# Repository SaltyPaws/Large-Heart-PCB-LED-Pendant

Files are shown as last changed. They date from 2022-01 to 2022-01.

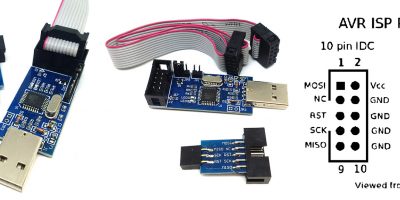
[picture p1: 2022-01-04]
images/usbasp_header-400x200.jpg

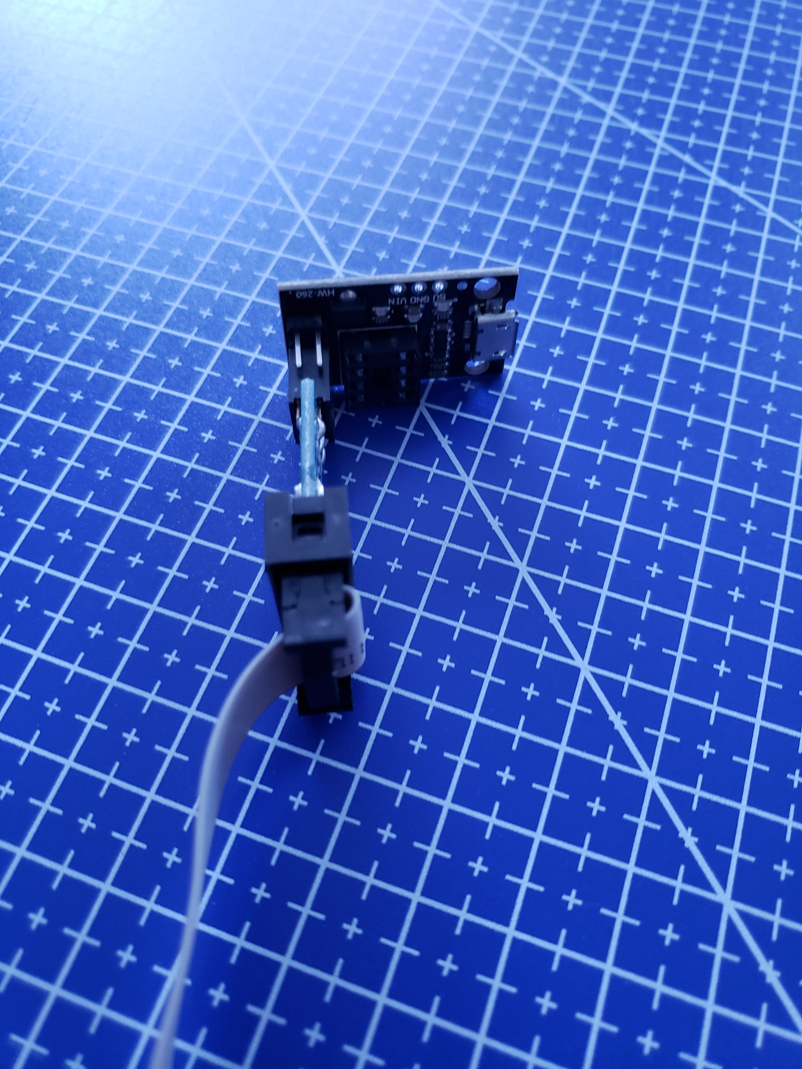
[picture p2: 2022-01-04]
images/20220103_123011.jpg

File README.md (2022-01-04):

# Large LED Heart PCB Pendant
> A large heart with 20 individually controllable LEDS using 4 pins on an ATtiny 45 with Charlieplexing
> This is an easy to solder project, as all components are trough hole, except for the large and easy to solder battery holder
> Who would not like to be pledged eternal love to by their valentine giving them a large blinky LED heart Pendant!

Large HEART PCB LED Pendant

## Table of Contents
* [General Info](#general-information)
* [Technologies Used](#technologies-used)
* [Features](#features)
* [Images](#images)
* [Setup](#setup)
* [Usage](#usage)
* [Project Status](#project-status)
* [Room for Improvement](#room-for-improvement)
* [Acknowledgements](#acknowledgements)
* [Contact](#contact)
<!-- * [License](#license) -->

## General Information
- I developed this project, in order to introduce my daughters to electronics. This pendant can be used to introduce STEAM concepts at many levels. It can be used to introduce electronics, teach trough hole assembly/soldering and programming.
- This is a basic demonstration of the Charlieplexing principle. The heart can be used stand alone or in a pendant.
- I used FreeCAD in order to design the heart shape. Unfortunately at the time of designing, the offset tool was not available in FreeCAD (I know there are work arounds), and I completed the snap on case design using Fusion360.
- I skipped the breadboard prototyping phase by using the proven Circuit design from designer2k2. The first version of the PCB worked as per design.
- For printing the case, I used PLA, 40% infill and 0.2mm layer height. It easily snaps onto the PCB, and while the stand offs include m3 thread, the M3 x6mm bolts are not required as the 45 degrees edge on the case holds it in place. I would not reccomend using without case as the back of a trough hole PCB can be demanding blood like a Vampire from Transylvania.
<!-- You don't have to answer all the questions - just the ones relevant to your project. -->

## Technologies Used
- Ubuntu 20.10 OS
- FreeCAD Realthunder branch (2021.10.15) for designing the heart shape
- KiCad 5.99.0+really5.1.10+dfsg1-1, release build
- Freerouting 1.4.5 (Current KiCad does not have an autorouter)
- Fusion 360 for designing the heart case
- Prusa slicer (1.4.0)
- Arduino IDE 1.8.19 for flashing firmware and uploading the code.
- Attiny core library (https://github.com/SpenceKonde/ATTinyCore)

## Features
This project has the following awesome features:
- uses 5 pins, in order to individually control 20 LEDs
- The project uses trough hole components (with exception of easy to solder battery holder for easy assembly)
- The 3D printed snap on case projects (young) fingers from the sharp spikes on the back of the trough hole PCB.
- I used the HW-260 and USBASP in order to program the ATtiny45. However, the ATtiny45 can also be programmed using the connector on the PCB.

## images
Large HEART PCB LED Pendant
Large HEART PCB LED Pendant
Large HEART PCB LED Pendant
Large HEART PCB LED Pendant
Large HEART PCB LED Pendant
Large HEART PCB LED Pendant
<!-- If you have screenshots you'd like to share, include them here. -->

## Setup
0) order PCB and parts (I used JLPCB, Aliexpress and Digikey)
1) Program the ATtiny45 chip using the HW-260 & USBASP programmer. You will need to flash the bootloader @1 MHZ and upload the .ino code. (https://www.instructables.com/ATtiny13AATtiny25ATtiny45ATtiny85-Programming-With/) Hint: use <CTRL>+<SHIFT>+<U> in order to upload using programmer.
2) Start printing the snap on case.
3) Heat up that iron and put the PCB together.
4) Snap on the snap on case.
5) Introduce STEAM or propose to your dearest.

## Usage
Simply switch the heart on/off as required.

## Project Status
Project is complete.

## Room for Improvement
The heart is rather large for a pendant. I may develop a smaller version based on surface mount components in the future.

Room for improvement:
- With the ATtiny 45 there is more memory space. It could be programmed to cycle trough more/longer patterns.
- An eye could be added to the 3d printed snap fit case, for pendant usage. Currently only the 3mm hole is available, which may be a bit small for strings.
- One of the M3 holes is covered by the switch. However, the case is snap fit and does not need the M3 hardware to stay in place.

## Acknowledgements
- Circuit and code was based on ATtiny Powered Christmas Tree
https://github.com/designer2k2/2d-xmas-tree
https://github.com/designer2k2/2d-xmas-tree
- USBASP pinout image from: kabelverdrahtungsschema.blogspot.com

- Many thanks to my daughters for relentless beta testing

## Contact
Created by [SaltyPaws](https://github.com/SaltyPaws) - feel free to contact me!

## License
This project is open source and available under the MIT License.

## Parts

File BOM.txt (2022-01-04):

R1-5 100 Ohm resistor (use different value for different colors)
R6 10k Ohm resistor
C1 10 10μF capacitor (106)
D1-20 5mm LEDs. I used alternating white and blue extra clear
BT1/2 BS10 Battery holder
SW1 EG2585-ND (Digikey)
Attiny ATTINY45-20PU

Programming
HW-260 ATtiny13A / ATtiny25 / ATtiny45 / ATtiny85 Pluggable ATTINY Development Programming Bare Board
USBASP programmer
USBASP 10 to 6 cable converter

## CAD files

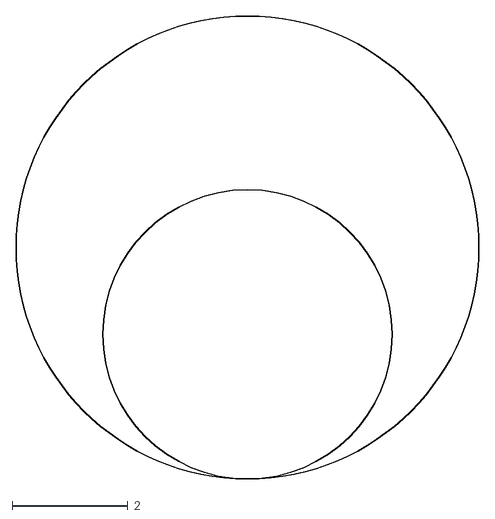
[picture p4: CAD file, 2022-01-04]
3D Print CAD/heart_v4-BodySketch.dxf
8.00 x 8.00

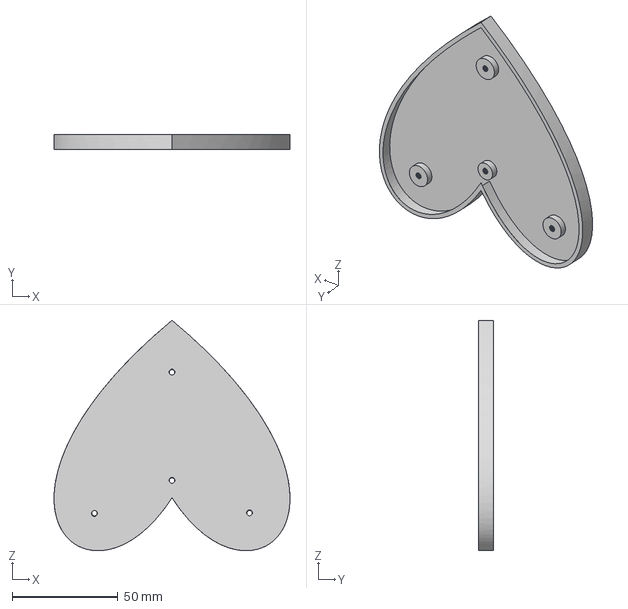
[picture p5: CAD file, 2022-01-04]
3D Print CAD/Heart_Case.step
111.7 x 7.00 x 109.1 mm

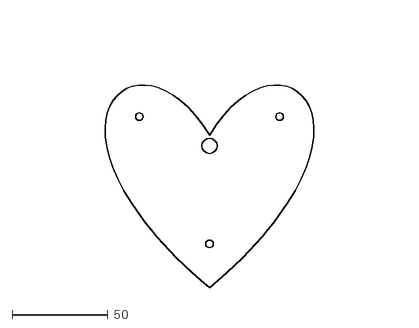
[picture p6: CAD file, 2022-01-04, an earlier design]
3D Print CAD/heart_v3-BodySketch.dxf
202.4 x 142.2

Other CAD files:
3D Print CAD/heart_v2.FCStd
3D Print CAD/heart_v1.FCStd
3D Print CAD/Heart_Case.3mf
3D Print CAD/Heart_Case.f3d
3D Print CAD/Heart_Case.iges

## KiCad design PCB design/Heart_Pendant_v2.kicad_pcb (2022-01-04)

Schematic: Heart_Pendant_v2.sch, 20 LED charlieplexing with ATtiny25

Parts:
BT1, BT2: Battery_Cell; Keystone_1058_1x2032-CoinCell_Inside
C1: C; 0805_Internal_Castellation
D1, D2, D3, D4, D5, D6, D7, D8, D9, D10, D11, D12, D13, D14, D15, D16, D17, D18, D19, D20: LED; 0805_Internal_Castellation
J1: ISP; Socket_Strip_Straight_2x03_Pitch2.54mm
R1, R2, R3, R4, R5: 75; 0805_Internal_Castellation
R6: 10k; 0805_Internal_Castellation
SW1: SW_SPDT; PCM12SMTR_inside
U1: ATTINY25-20SU; SOIC-8_Inside

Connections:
/MISO: J1.1, R2.2, U1.6 (PB1(MISO/DO/AIN1/OC0B/OC1A/PCINT1))
/MOSI: J1.4, R1.2, U1.5 (PB0(MOSI/DI/SDA/AIN0/OC0A/~OC1A~/AREF/P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)
/RESET: J1.5, R6.2, U1.1 (PB5(~RESET~/dW/ADC0/PCINT5))
/SCK: J1.3, R3.2, U1.7 (PB2(SCK/USCK/SCL/T0/INT0/ADC1/PCINT2))
/VCC: C1.1, J1.2, R6.1, SW1.2 (B), U1.8 (VCC)
GND: BT1.2, BT2.2, C1.2, J1.6, U1.4 (GND)
unnamed: BT1.1, BT2.1, SW1.1 (A)
unnamed: D1.1, D2.2, D3.2, D4.1, D11.2, D12.1, D17.2, D18.1, R2.1
unnamed: D1.2, D2.1, D9.2, D10.1, D15.2, D16.1, D19.2, D20.1, R1.1
unnamed: D3.1, D4.2, D5.2, D6.1, D9.1, D10.2, D13.2, D14.1, R3.1
unnamed: D5.1, D6.2, D7.2, D8.1, D11.1, D12.2, D15.1, D16.2, R4.1
unnamed: D7.1, D8.2, D13.1, D14.2, D17.1, D18.2, D19.1, D20.2, R5.1
unnamed: R4.2, U1.2 (PB3(XTAL1/CLKI/~OC1B~/ADC3/PCINT3))
unnamed: R5.2, U1.3 (PB4(XTAL2/CLKO/OC1B/ADC2/PCINT4))

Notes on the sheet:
R = Led R / 2 (current flows always through 2)
20 LED Charlieplexing

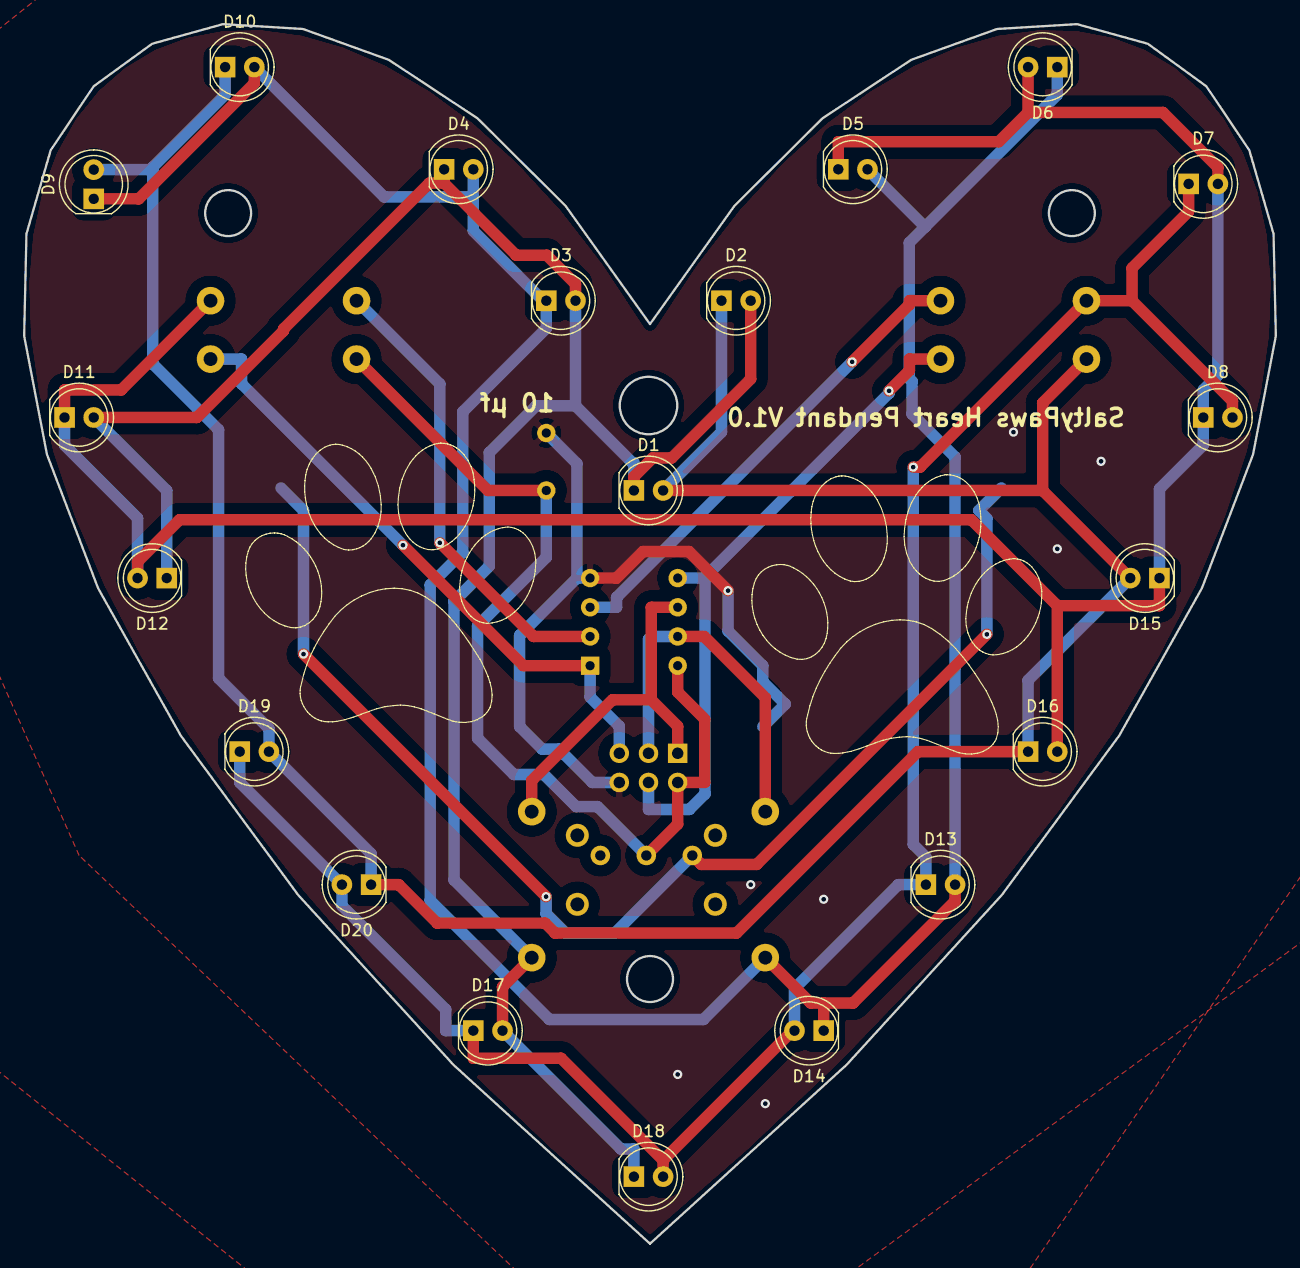
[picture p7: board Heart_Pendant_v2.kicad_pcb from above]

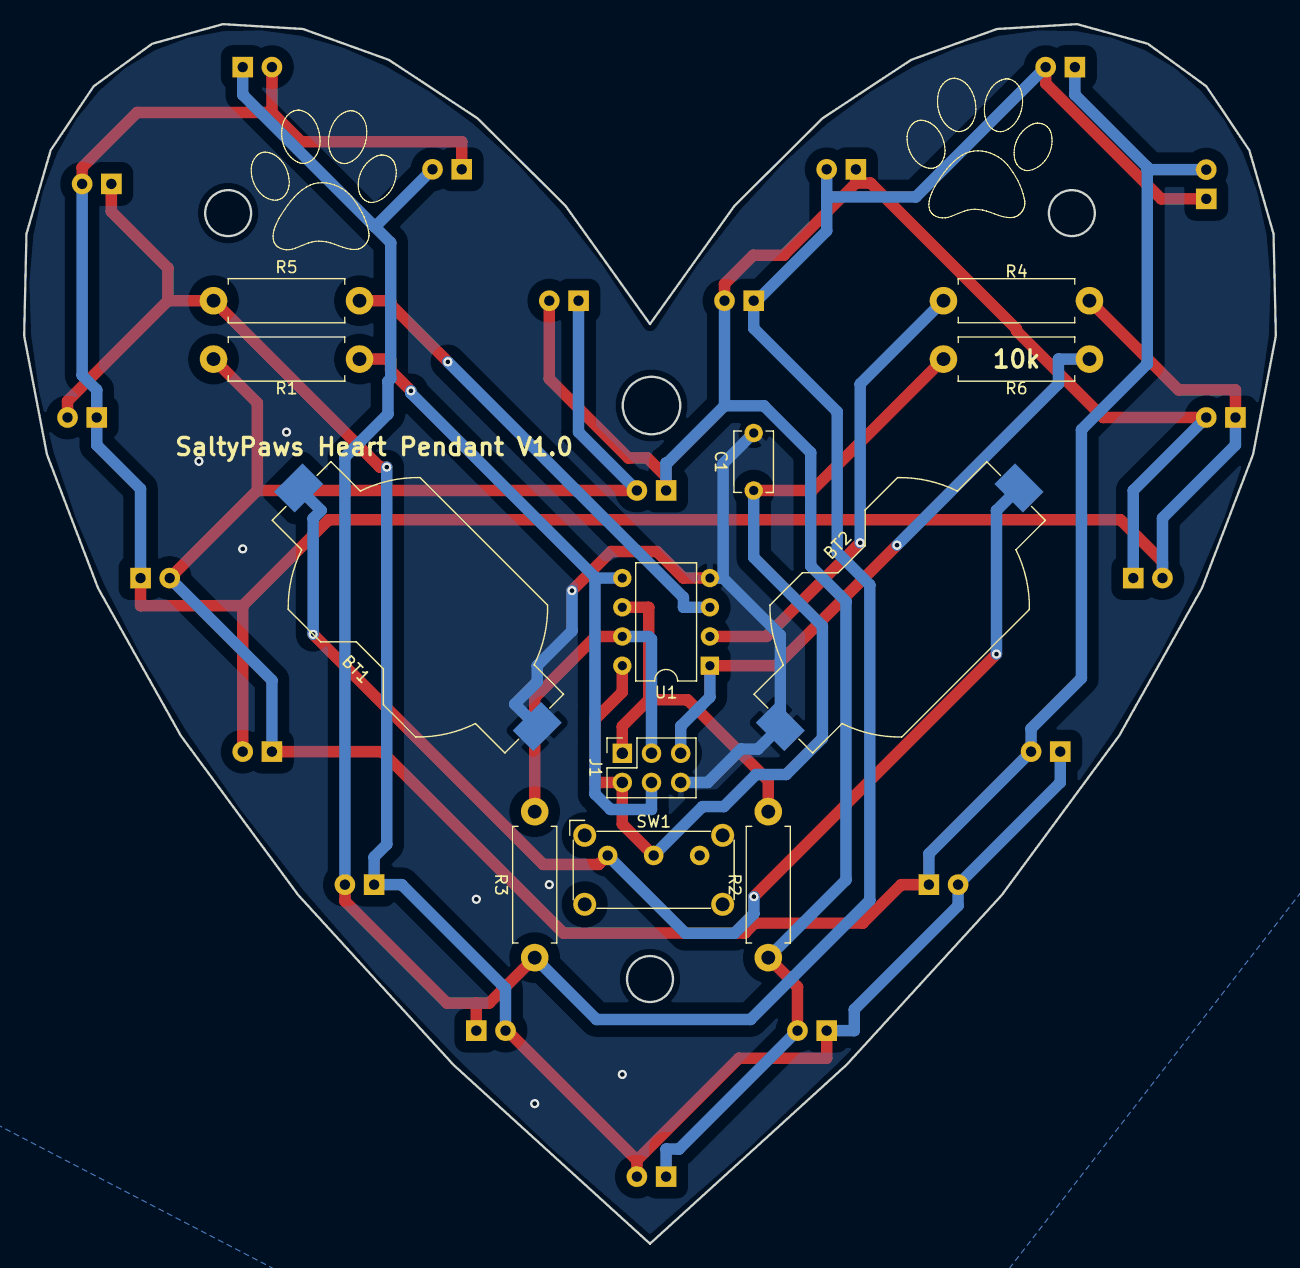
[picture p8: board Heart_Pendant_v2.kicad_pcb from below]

Board: 2 copper layers, 108.9 x 106.1 mm, 32 parts (12 on the bottom side), 14 nets.

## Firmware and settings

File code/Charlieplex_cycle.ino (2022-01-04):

/*
 * MIT licence.
 * 
 * Code modified from original by Saltypaws 22. Changes:
 * Changed pattern. The ATtiny45 can hold many more lines than the 14 from the ATtiny25
 * Added lookup table to match LEDs on table
 * 
 *  
 */


/* 
 2D XMAS Tree Code
 charlieplexing christmas decoration
 5 Pins with 20 LED´s
 ATtiny25, 1MHZ Internal Clock, no BOD
 Hosted on Github: 
 
 https://github.com/designer2k2/2d-xmas-tree
 Made by:
 
 https://www.designer2k2.at
  MIT License
  
  Copyright (c) [2018] [Stephan Martin]
  
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
  THE SOFTWARE IS PROVIDED "AS IS", WITHOUT WARRANTY OF ANY KIND, EXPRESS OR
  IMPLIED, INCLUDING BUT NOT LIMITED TO THE WARRANTIES OF MERCHANTABILITY,
  FITNESS FOR A PARTICULAR PURPOSE AND NONINFRINGEMENT. IN NO EVENT SHALL THE
  AUTHORS OR COPYRIGHT HOLDERS BE LIABLE FOR ANY CLAIM, DAMAGES OR OTHER
  LIABILITY, WHETHER IN AN ACTION OF CONTRACT, TORT OR OTHERWISE, ARISING FROM,
  OUT OF OR IN CONNECTION WITH THE SOFTWARE OR THE USE OR OTHER DEALINGS IN THE
  SOFTWARE.
*/

#include <avr/pgmspace.h>

//Enter the light pattern here:
//use the online generator: https://designer2k2.github.io/2d-xmas-tree/
//dont forget to update the number of rows if changed

/*static const bool state_table[14][21] PROGMEM = {
                 {1,1,0,0,0,0,0,0,0,0,0,0,0,0,0,0,0,0,0,0},
                 {0,0,1,1,1,1,0,0,0,0,0,0,0,0,0,0,0,0,0,0},
                 {0,0,0,0,0,0,1,0,1,0,1,1,0,0,0,0,0,0,0,0},
                 {0,0,0,0,0,0,0,1,0,1,0,0,1,0,0,0,1,0,0,0},
                 {0,0,0,0,0,0,0,0,0,0,0,0,0,1,1,1,0,1,1,1},
                 {0,0,0,0,0,0,0,0,0,0,0,0,0,0,0,0,0,0,1,0},
                 {0,0,1,0,0,0,0,0,1,0,0,0,0,0,0,0,1,1,0,0},
                 {1,0,0,1,0,0,0,0,0,0,0,1,0,0,0,0,0,0,0,0},
                 {0,0,0,0,0,1,1,1,0,0,0,0,0,1,0,0,0,0,0,0},
                 {0,0,0,0,0,0,0,0,0,0,0,0,0,0,1,1,0,0,0,0},
                 {0,1,0,0,1,0,0,0,0,0,1,0,1,0,0,0,0,0,0,0},
                 {0,0,1,0,0,0,0,0,1,0,0,0,0,0,0,0,1,1,0,0},
                 {0,0,0,0,0,0,0,0,0,1,0,0,0,0,0,0,0,0,0,1},
                 {0,0,0,0,0,0,0,0,0,0,0,0,0,0,0,0,0,0,1,0}
};*/


static const bool state_table[20][21] PROGMEM = {
                 {1,0,0,0,0,0,0,0,0,0,0,0,0,0,0,0,0,0,0,0},
                 {0,1,0,0,0,0,0,0,0,0,0,0,0,0,0,0,0,0,0,0},
                 {0,0,1,0,0,0,0,0,0,0,0,0,0,0,0,0,0,0,0,0},
                 {0,0,0,1,0,0,0,0,0,0,0,0,0,0,0,0,0,0,0,0},
                 {0,0,0,0,1,0,0,0,0,0,0,0,0,0,0,0,0,0,0,0},
                 {0,0,0,0,0,1,0,0,0,0,0,0,0,0,0,0,0,0,0,0},
                 {0,0,0,0,0,0,1,0,0,0,0,0,0,0,0,0,0,0,0,0},
                 {0,0,0,0,0,0,0,1,0,0,0,0,0,0,0,0,0,0,0,0},
                 {0,0,0,0,0,0,0,0,1,0,0,0,0,0,0,0,0,0,0,0},
                 {0,0,0,0,0,0,0,0,0,1,0,0,0,0,0,0,0,0,0,0},
                 {0,0,0,0,0,0,0,0,0,0,1,0,0,0,0,0,0,0,0,0},
                 {0,0,0,0,0,0,0,0,0,0,0,1,0,0,0,0,0,0,0,0},
                 {0,0,0,0,0,0,0,0,0,0,0,0,1,0,0,0,0,0,0,0},
                 {0,0,0,0,0,0,0,0,0,0,0,0,0,1,0,0,0,0,0,0},
                 {0,0,0,0,0,0,0,0,0,0,0,0,0,0,1,0,0,0,0,0},
                 {0,0,0,0,0,0,0,0,0,0,0,0,0,0,0,1,0,0,0,0},
                 {0,0,0,0,0,0,0,0,0,0,0,0,0,0,0,0,1,0,0,0},
                 {0,0,0,0,0,0,0,0,0,0,0,0,0,0,0,0,0,1,0,0},
                 {0,0,0,0,0,0,0,0,0,0,0,0,0,0,0,0,0,0,1,0},
                 {0,0,0,0,0,0,0,0,0,0,0,0,0,0,0,0,0,0,0,1}
};

#define NumRows 20  //default is 14 (and about the space limit)

//the delay in ms between the patterns:
#define pattern_delay 500

//intro time (how long the random change happens) in ms:
#define introtime 10000

//time a led is on in us:
//increase this to have the leds "flicker"
#define ondelay 1000


//-------------------------------------------------------------------------------------
//below is the code to make this all happen, modify to make even fancier effects as you wish!

//This holds the pin configuration to make the 20 led charlieplexing,
//only 1 in PROGMEM, as the FLASH is full, but both are too large for RAM.
int pinvcc[] = {0,1,1,2,2,3,3,4,0,2,1,3,2,4,0,3,1,4,0,4};
const PROGMEM int pingnd[] = {1,0,2,1,3,2,4,3,2,0,3,1,4,2,3,0,4,1,4,0};

//placeholder for all current leds:
bool ledstate[] = {0,0,0,0,0,0,0,0,0,0,0,0,0,0,0,0,0,0,0,0}; 

// Coversion of LED positions to heart
static const uint8_t  LEDPos[20]={17,16,19,18,11,10,8,9,3,2,0,1,4,5,6,7,14,15,12,13};
//Used to translate LED pos
uint8_t j=0;

unsigned long lasttime, lastintrotime;

int iState;

void setup() {
  //Need to define the Pins as input (defaults)
  tristate();

  // disable ADC (power saving):
  ADCSRA = 0;  

  //init the time with 0
  lasttime = 0;
  lastintrotime = introtime;

  //start with the first pattern
  iState = 0;

}

void loop(){
  // put your main code here, to run repeatedly:

  // every 100ms change a random led to a random state
  if(millis()<lastintrotime){
    if(millis()>(lasttime+10)){
      int ledtoset = random(20);
      bool ledbool = random(2);
      ledstate[ledtoset] = ledbool;
      lasttime = millis();
    }
  }else{
  //loop trough the states in state_table  

    if(millis()>(lasttime+pattern_delay)){
      for (int i=0; i<20; i++) {
        int state = pgm_read_word(&state_table[iState][i]);

        //PROGMEM with bool gives sometimes strange results, this fixes it:
        if (state==256){
          state = 0;
        }
        
        ledstate[i] = state;
      }
      iState = iState + 1;
      if(iState>=NumRows){
        iState = 0;
        lastintrotime = millis() + introtime;
      }
      lasttime = millis();
    }
  }

  showleds(); 
  
}

//-------------------------------------------------------------------------------------

void showleds(){
  // this cycles trough all the leds in the array and show them.
  
  for (int i=0; i<20; i++) {
    uint8_t j=LEDPos[i];
   bool state = ledstate[j];
   showled(j,state);
  }
  
}

void showled(int led, bool state){
  //this outputs the led state

  if(state==true){
    //Lookup the pin for high and low:
    int pvcc = pinvcc[led];
    int pgnd = pgm_read_word(&pingnd[led]);

    //set the pinmode for it:
    pinMode(pvcc,OUTPUT);
    pinMode(pgnd,OUTPUT);

    //write the status:
    digitalWrite(pvcc,HIGH);
    digitalWrite(pgnd,LOW);

    //wait a short time to let the LED shine
    delayMicroseconds(ondelay);
    
    //ensure its all turned off properly for the next state
    tristate();
  }
 
}

void tristate(){
  //This tristates all pins
  for (int i=0; i<5; i++) {
   pinMode(i,INPUT);   //Input state
   digitalWrite(i,LOW);//ensure pullups are off.
  }
}
